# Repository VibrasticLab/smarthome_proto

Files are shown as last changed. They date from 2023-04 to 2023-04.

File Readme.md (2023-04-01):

# SmartHome Module

This repository contains development files for smarthome monitoring prototyping,
which intended for student final project.

Currently doesnt support any control mechanism, only measuring.

## Multi Module Version 1

### Sensors Options
- Temperature/Humidity Sensors (I2C)
    + HTU21D: [Tokped](https://www.tokopedia.com/akhishop/htu21d-temperature-and-humidity-sensor-module)
    + SHT20: [Tokped](https://www.tokopedia.com/akhishop/sht20-digital-temperature-and-humidity-sensor-module-i2c-communication)
    + SHT31-D: [Tokped](https://www.tokopedia.com/akhishop/sht31-d-temperature-humidity-sensor-module)
    + GY-213V: [Tokped](https://www.tokopedia.com/cncstorebandung/gy-213v-hdc1080-high-precision-temperature-and-humidity-sensor-module)
- Light Intensity Sensors (I2C)
    + GY302/BH1750: [Tokped](https://www.tokopedia.com/akhishop/gy-302-light-intensity-bh1750-module-sensor-intensitas-cahaya)
- CO2 Air (Analog)
    + MG-811: [Tokped](https://www.tokopedia.com/khursiot/dfrobot-analog-co2-gas-sensor-for-arduino-mg-811-sensor)
- MEMS Microphone (I2S)
    + INMP441: [Tokped](https://www.tokopedia.com/aifrobotic/inmp441-omnidirectional-microphone-module-mems-i2s-interface)

### ESP32 Pinout

NodeMCU Module: [Tokped](https://www.tokopedia.com/temins/esp32-esp-32-arduino-wifi-bluetooth-iot-development-board-micro-usb)

| I/O | Func | Connect |
|:---:|:----:|:---:|
| EN | RESET | Pull-up Button |
| 0 | FLASH | Pull-up Button |
| 1 | TX | UART0 |
| 2 | IND | LED |
| 3 | RX | UART0 |
| 13 | SPI WS | MIC |
| 14 | SPI SCK | MIC |
| 15 | BOOT-LOG | Pull-done Resistor |
| 21 | SDA | I2C Line |
| 22 | SCL | I2C Line |
| 23 | SPI DATA | MIC |
| 33 | ADC | VBAT |
| 34 | ADC | CO2 |

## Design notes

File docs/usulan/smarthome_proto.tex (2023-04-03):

\documentclass[a4paper,12pt,oneside,pdflatex,italian,final,twocolumn]{article}

\usepackage[utf8]{inputenc}
\usepackage{parallel}
\usepackage{siunitx}
\usepackage{booktabs}
\usepackage{fancyhdr}
\usepackage{subcaption}
\usepackage{listings}
\usepackage{hyperref}
\usepackage{pdfpages}
\usepackage{smartdiagram}
\usepackage{verbatim}

\usepackage[export]{adjustbox}
\usepackage[margin=0.5in]{geometry}
\addtolength{\topmargin}{0in}

\usepackage{libertine}
\renewcommand*\familydefault{\sfdefault}
\usepackage[T1]{fontenc}

\urlstyle{sf}
\hypersetup{
	colorlinks=true, %set true if you want colored links
	linktoc=all,     %set to all if you want both sections and subsections linked
	linkcolor=blue,  %choose some color if you want links to stand out
	urlcolor=blue,   %url color
}

\smartdiagramset{text width=2cm,module x sep= 3.4,back arrow disabled=true,}

\title{Smarthome Measurement Node Prototype}
\author{Achmadi ST MT}
\date{April 2023}

\begin{document}
	\pagestyle{fancy}

	\lhead{VibrasticLab}
	\chead{\today}
	\rhead{Specification Document v1.0}

	\onecolumn

	\begin{figure}

	\end{figure}\begin{minipage}{0.47\textwidth}
		\centering

	\end{minipage}
	\hfill
	\begin{minipage}{0.47\textwidth}
		\raggedleft
		\Huge \textbf{Smarthome Measurement Node}
	\end{minipage}

	\begin{figure}
		\begin{minipage}{0.47\textwidth}

			\section{Overview}
			\begin{itemize}
				\item Battery AAA Operated
				\item Low-Power WiFi Cient
				\item Re-Programmable Firmware
				\item Analog, I2S, and I2C interfaces
				\item Indicator LEDs Array
			\end{itemize}

		\end{minipage}
		\hfill
		\begin{minipage}{0.47\textwidth}
			\centering
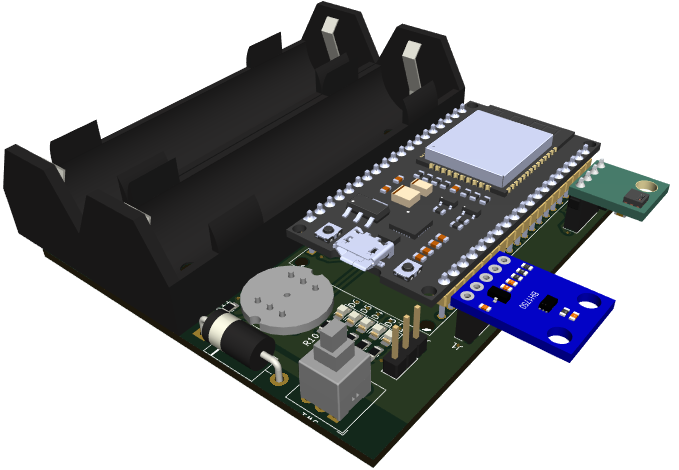
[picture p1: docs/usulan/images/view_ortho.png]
			

	\end{minipage}
	\end{figure}

	\raggedright
	\section{Main Unit Part}

	\centering
	\begin{figure}[!ht]
		\centering
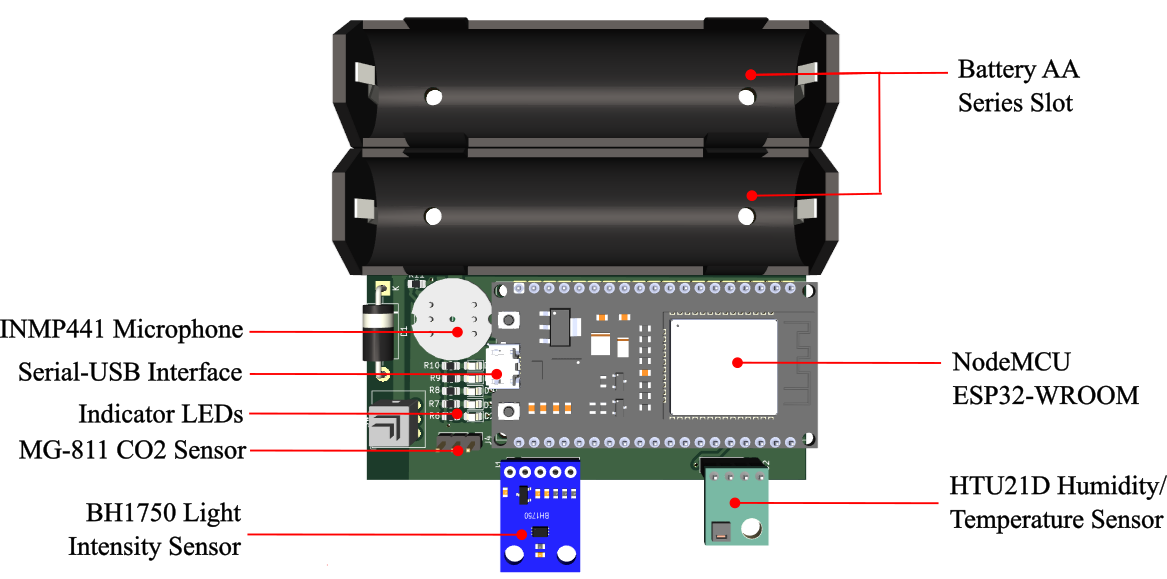
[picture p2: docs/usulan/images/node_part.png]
		
		\caption{Prototype Unit Parts}
	\end{figure}

	\raggedright
	\section{Data Exchange Flow}

	\smartdiagram[flow diagram:horizontal]{Multi Sensor Node,
		MQTT or HTTP Server, Data Bank Server, Data Fetch API, Python or Matlab Analysis}\\

	\vspace{5pt}

	\textbf{NOTES:} Its recommended to use Local Server infrastructure, preferably in accessable server room during development phase.

	\raggedright
	\section{PCB Design}

	\newpage
	\includepdf[pages=-,angle=-90]{pdf/nodemcu_based.pdf}

	\newpage
	\includepdf[pages=-,angle=-90]{pdf/bom.pdf}

	\raggedright
	\section{Project Repository}

	Current project repository: \href{https://github.com/VibrasticLab/smarthome_proto}{Github VibrasticLab}

	\raggedright
	\section{Development Constraints/Obstacles}

	Some development constraints/obstacles:

	\begin{itemize}
		\item Time span, including: PCB building time, firmware implementation, testing and calibration, server building.

		\item Calibration process, including: standards, controlled test environment, and already available measurement tools.

		\item Personel requirement, including: programmers (either embedded or backend server), project managers/administrator, purchasing staff, etc.

		\item Components handling, for example:

		\begin{itemize}
			\item MG-811 CO2 sensor requires heating to operate, thus consume high power from battery.

			\item MG-811 CO2 sensor are very expensive and limited local stock.

			\item Light Intensity might influenced by placement angle.

			\item Mic INMP411 requires good digital signal processing in embedded programming manner.
		\end{itemize}

	\end{itemize}

	\raggedright
	\section{Cost Estimation}

	\subsection{Unit Cost}

	\begin{tabular}{|l|l|l|}
		\toprule
		Item & Price-Qty & URL \\
		\midrule
		NodeMCU ESP32 & Rp. 66.800 & \href{https://www.tokopedia.com/temins/esp32-esp-32-arduino-wifi-bluetooth-iot-development-board-micro-usb}{Tokped} \\
		HTU21D & Rp. 35.000 & \href{https://www.tokopedia.com/akhishop/htu21d-temperature-and-humidity-sensor-module}{Tokped} \\
		BH1750 & Rp. 20.000 & \href{https://www.tokopedia.com/akhishop/gy-302-light-intensity-bh1750-module-sensor-intensitas-cahaya}{Tokped} \\
		MG-811 CO2 & Rp. 895.000 & \href{https://www.tokopedia.com/khursiot/dfrobot-analog-co2-gas-sensor-for-arduino-mg-811-sensor}{Tokped} \\
		R 0805 & Rp. 2.000 & \href{https://www.tokopedia.com/thingie/resistor-0805-5-102-1k-ohm-smd-2012}{Tokped} \\
		LED 0805 & Rp. 2.000 & \href{https://www.tokopedia.com/easyware-id/led-smd-0805-super-bright-all-color-led-smd-0805-semua-warna-putih}{Tokped} \\
		Diode 1N4007 & Rp. 500 & \href{https://www.tokopedia.com/dx-tronics/diode-1n4007-in4007-dioda-rectifier-1a-1000v}{Tokped} \\
		Mic INMP411 & Rp. 40.000 & \href{https://www.tokopedia.com/aifrobotic/inmp441-omnidirectional-microphone-module-mems-i2s-interface}{Tokped} \\
		Header/Cable/Switches & Rp. 50.000 & \href{https://www.tokopedia.com/eltech-online}{Tokped} \\
		PCB Fabrication & Rp. 50.000 & \href{https://www.tokopedia.com/geraicerdas/cetak-pcb-1-keping-single-double-layer-rapid-prototyping-satuan}{Tokped} \\
		Shipping Cost Overall & Rp. 50.000 & - \\
		\midrule
		Total & Rp. 1.211.300  & - \\
		\bottomrule
	\end{tabular}

	\vspace{5pt}
	\textbf{Notes:} Its recommended to build multiple units to monitor single room in different multiple placements.

	\subsection{Personel Cost}

	\begin{tabular}{|l|l|l|l|}
		\toprule
		Jobs & Price & Personel & Alternative \\
		\midrule
		PCB Assembly and QC & Rp. 1.000.000 & Achmadi & Tim LabFisis \\
		Firmware Developer & Rp. 2.000.000 & Achmadi & Tim Labkom \\
		Purchasing Staff & Rp. 500.000 & - & Asisten LabVibrastik \\
		Project Manager/Admin & Rp. 1.000.000 & Ammar & Asisten LabVibrastik \\
		Calibration Team & Rp. 1.000.000 & - &  Asisten LabVibrastik \\
		Backend Developer & Rp. 2.000.000 & Pras & Tim Labkom \\
		Server Infastructure Team & Rp. 500.000 & - & Tim Labkom \\
		\midrule
		Total & Rp. 8.000.000  & - & - \\
		\bottomrule
	\end{tabular}

	\vspace{5pt}
	\textbf{Note:} This the recommended jobdesc list, but the price here are only proposed estimation and still negotiable.

	\subsection{Development Cost}

	\begin{tabular}{|l|l|l|}
		\toprule
		Item & Qty & Price \\
		\midrule
		Measurement Node Cost & 5 prototype units & Rp. 6.056.500 \\
		Personel/Team & one-time project & Rp. 8.000.000 \\
		\midrule
		Total & - & Rp. 14.056.500 \\
		\bottomrule
	\end{tabular}
\end{document}

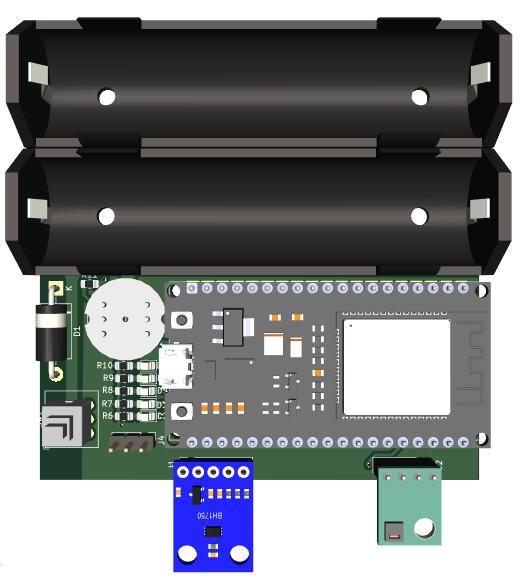
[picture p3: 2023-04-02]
docs/usulan/images/view_top.png

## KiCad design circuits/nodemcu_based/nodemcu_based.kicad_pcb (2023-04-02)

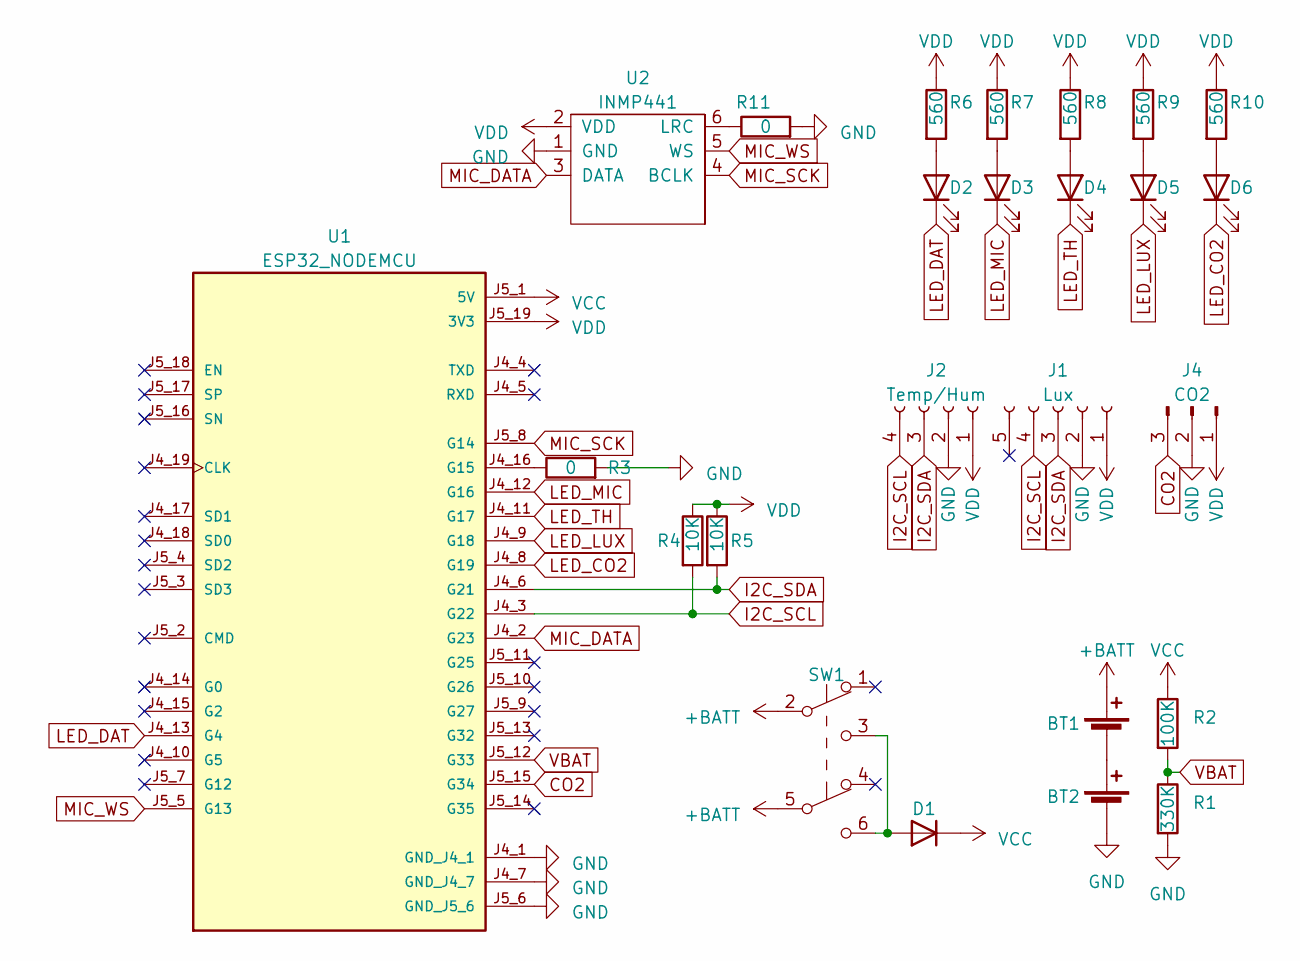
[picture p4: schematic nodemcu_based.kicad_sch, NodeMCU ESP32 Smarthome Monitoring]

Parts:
BT1, BT2: Battery_Cell; BatteryHolder_MPD_BH-18650-PC2
D1: D; D_DO-201_P15.24mm_Horizontal
D2, D3, D4, D5, D6: LED; LED_0805_2012Metric_Pad1.15x1.40mm_HandSolder
J1: Lux; PinSocket_1x05_P2.54mm_Vertical
J2: Temp/Hum; PinSocket_1x04_P2.54mm_Vertical
J4: CO2; PinHeader_1x03_P2.54mm_Vertical
R1: 330K; R_0805_2012Metric_Pad1.20x1.40mm_HandSolder
R2: 100K; R_0805_2012Metric_Pad1.20x1.40mm_HandSolder
R3, R11: 0; R_0805_2012Metric_Pad1.20x1.40mm_HandSolder
R4, R5: 10K; R_0805_2012Metric_Pad1.20x1.40mm_HandSolder
R6, R7, R8, R9, R10: 560; R_0805_2012Metric_Pad1.20x1.40mm_HandSolder
SW1: SW_Push_DPDT; SW_Push_2P2T_Toggle_CK_PVA2OAH5xxxxxxV2
U1: ESP32_NODEMCU; MODULE_ESP32_NODEMCU
U2: INMP441

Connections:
+BATT: BT1.1 (+), SW1.2 (B), SW1.5 (B)
CO2: J4.3, U1.J5_15 (G34)
GND: BT2.2 (-), J1.2, J2.2, J4.2, R1.2, R3.2, R11.2, U1.J4_1 (GND_J4_1), U1.J4_7 (GND_J4_7), U1.J5_6 (GND_J5_6), U2.1 (GND)
I2C_SCL: J1.4, J2.4, R4.2, U1.J4_3 (G22)
I2C_SDA: J1.3, J2.3, R5.2, U1.J4_6 (G21)
LED_CO2: D6.1 (K), U1.J4_8 (G19)
LED_DAT: D2.1 (K), U1.J4_13 (G4)
LED_LUX: D5.1 (K), U1.J4_9 (G18)
LED_MIC: D3.1 (K), U1.J4_12 (G16)
LED_TH: D4.1 (K), U1.J4_11 (G17)
MIC_DATA: U1.J4_2 (G23), U2.3 (DATA)
MIC_SCK: U1.J5_8 (G14), U2.4 (BCLK)
MIC_WS: U1.J5_5 (G13), U2.5 (WS)
unnamed: BT1.2 (-), BT2.1 (+)
unnamed: D1.2 (A), SW1.3 (C), SW1.6 (C)
unnamed: D2.2 (A), R6.2
unnamed: D3.2 (A), R7.2
unnamed: D4.2 (A), R8.2
unnamed: D5.2 (A), R9.2
unnamed: D6.2 (A), R10.2
unnamed: R3.1, U1.J4_16 (G15)
unnamed: R11.1, U2.6 (LRC)
VBAT: R1.1, R2.2, U1.J5_12 (G33)
VCC: D1.1 (K), R2.1, U1.J5_1 (5V)
VDD: J1.1, J2.1, J4.1, R4.1, R5.1, R6.1, R7.1, R8.1, R9.1, R10.1, U1.J5_19 (3V3), U2.2 (VDD)

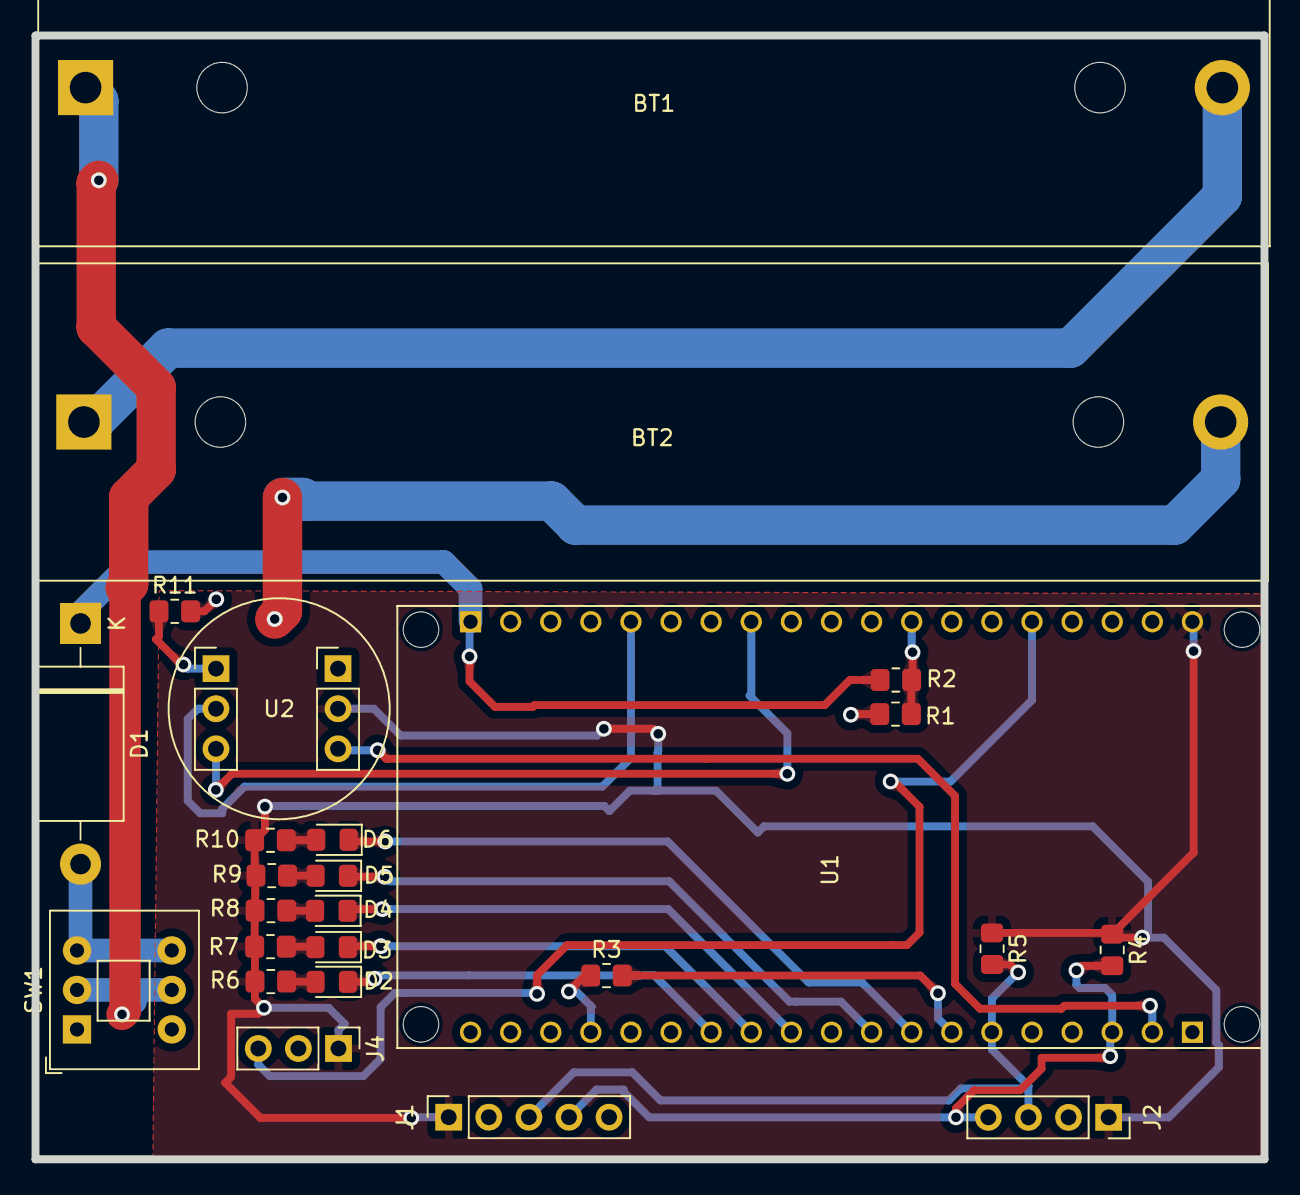
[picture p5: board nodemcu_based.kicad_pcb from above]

Board: 2 copper layers, 77.8 x 71.2 mm, 25 parts (0 on the bottom side), 25 nets.

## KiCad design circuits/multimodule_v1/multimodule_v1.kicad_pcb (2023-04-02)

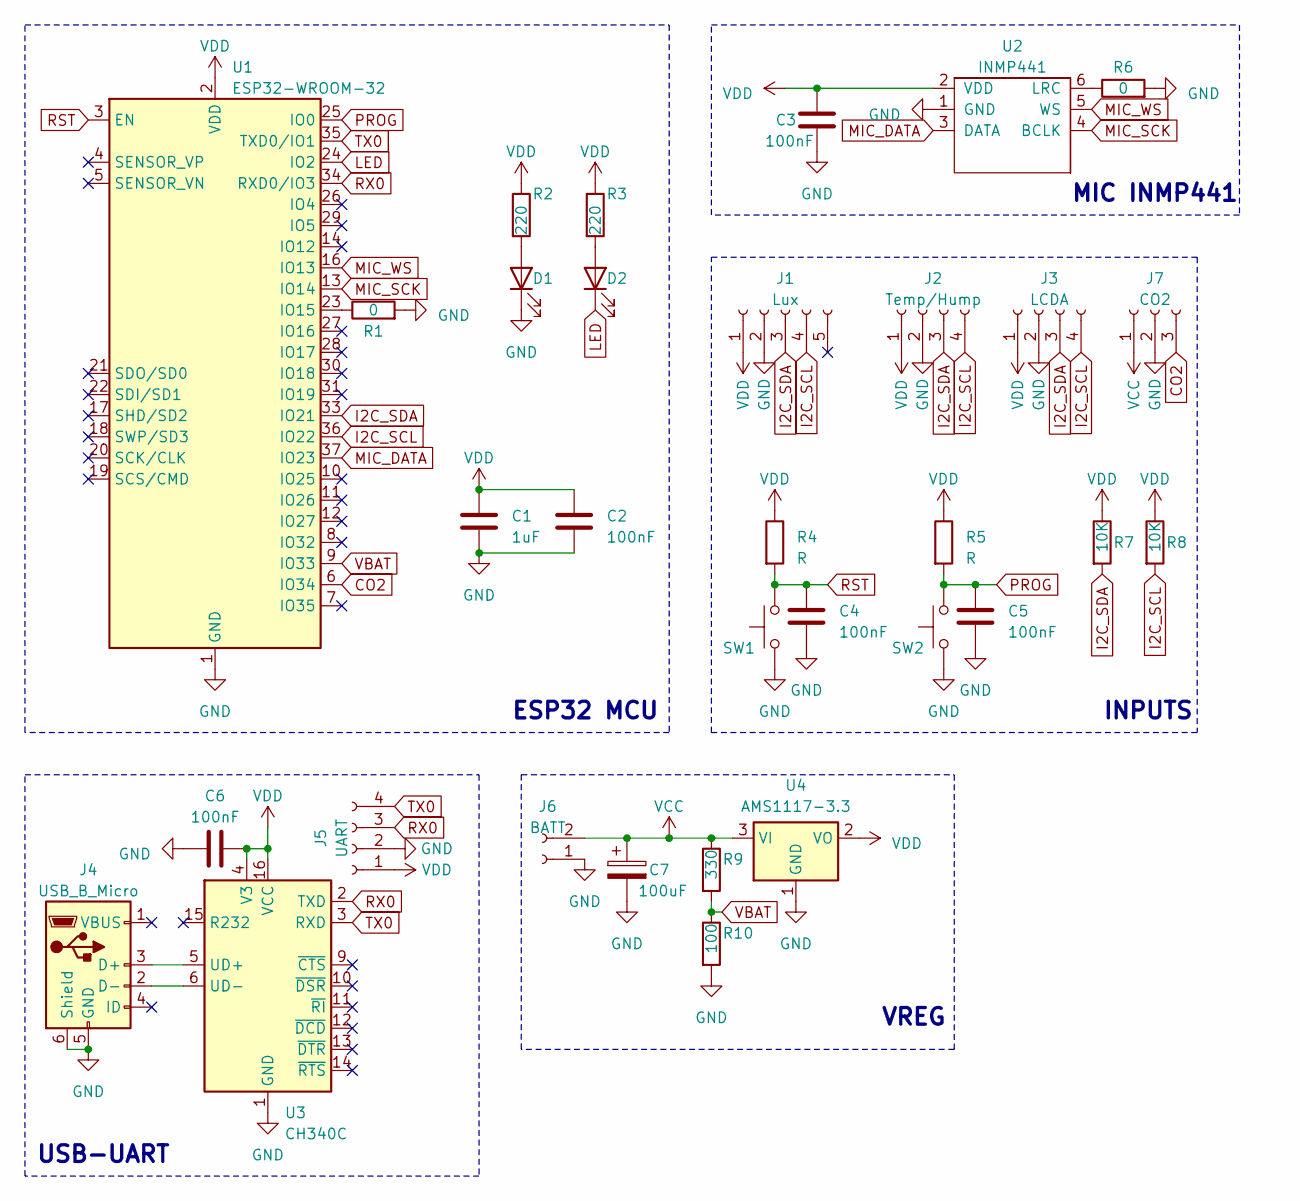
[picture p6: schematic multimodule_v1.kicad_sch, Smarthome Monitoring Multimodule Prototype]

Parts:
C1: 1uF; C_0805_2012Metric_Pad1.18x1.45mm_HandSolder
C2, C3, C4, C5, C6: 100nF; C_0805_2012Metric_Pad1.18x1.45mm_HandSolder
C7: 100uF; CP_Elec_4x5.8
D1, D2: LED; LED_0805_2012Metric_Pad1.15x1.40mm_HandSolder
J1: Lux; PinSocket_1x05_P2.54mm_Vertical
J2: Temp/Hump; PinSocket_1x04_P2.54mm_Vertical
J3: LCDA; PinSocket_1x04_P2.54mm_Vertical
J4: USB_B_Micro; USB_Micro-B_Wuerth_629105150521
J5: UART; PinHeader_1x04_P2.54mm_Vertical
J6: BATT; TerminalBlock_4Ucon_1x02_P3.50mm_Horizontal
J7: CO2; PinHeader_1x03_P2.54mm_Vertical
R1, R6: 0; R_0805_2012Metric_Pad1.20x1.40mm_HandSolder
R2, R3: 220; R_0805_2012Metric_Pad1.20x1.40mm_HandSolder
R4, R5: R; R_0805_2012Metric_Pad1.20x1.40mm_HandSolder
R7, R8: 10K; R_0805_2012Metric_Pad1.20x1.40mm_HandSolder
R9: 330; R_0805_2012Metric_Pad1.20x1.40mm_HandSolder
R10: 100; R_0805_2012Metric_Pad1.20x1.40mm_HandSolder
SW1, SW2: SW_Push; SW_PUSH_6mm
U1: ESP32-WROOM-32
U2: INMP441
U3: CH340C; SOIC-16_3.9x9.9mm_P1.27mm
U4: AMS1117-3.3; SOT-223-3_TabPin2

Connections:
CO2: J7.3, U1.6 (IO34)
GND: C1.2, C2.2, C3.2, C4.2, C5.2, C6.1, C7.2, D1.1 (K), J1.2, J2.2, J3.2, J4.5 (GND), J4.6 (Shield), J5.2, J6.1, J7.2, R1.2, R6.2, R10.2, SW1.1, SW2.1, U1.1 (GND), U1.15 (GND), U1.38 (GND), U1.39 (GND), U2.1 (GND), U3.1 (GND), U4.1 (GND)
I2C_SCL: J1.4, J2.4, J3.4, R8.2, U1.36 (IO22)
I2C_SDA: J1.3, J2.3, J3.3, R7.2, U1.33 (IO21)
LED: D2.1 (K), U1.24 (IO2)
MIC_DATA: U1.37 (IO23), U2.3 (DATA)
MIC_SCK: U1.13 (IO14), U2.4 (BCLK)
MIC_WS: U1.16 (IO13), U2.5 (WS)
unnamed: D1.2 (A), R2.2
unnamed: D2.2 (A), R3.2
unnamed: J4.3 (D+), U3.5 (UD+)
unnamed: J4.2 (D-), U3.6 (UD-)
unnamed: R1.1, U1.23 (IO15)
unnamed: R6.1, U2.6 (LRC)
PROG: C5.1, R5.2, SW2.2, U1.25 (IO0)
RST: C4.1, R4.2, SW1.2, U1.3 (EN)
RX0: J5.3, U1.34 (RXD0/IO3), U3.2 (TXD)
TX0: J5.4, U1.35 (TXD0/IO1), U3.3 (RXD)
VBAT: R9.2, R10.1, U1.9 (IO33)
VCC: C7.1, J6.2, J7.1, R9.1, U4.3 (VI)
VDD: C1.1, C2.1, C3.1, C6.2, J1.1, J2.1, J3.1, J5.1, R2.1, R3.1, R4.1, R5.1, R7.1, R8.1, U1.2 (VDD), U2.2 (VDD), U3.4 (V3), U3.16 (VCC), U4.2 (VO)

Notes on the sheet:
USB-UART
ESP32 MCU
VREG
INPUTS
MIC INMP441

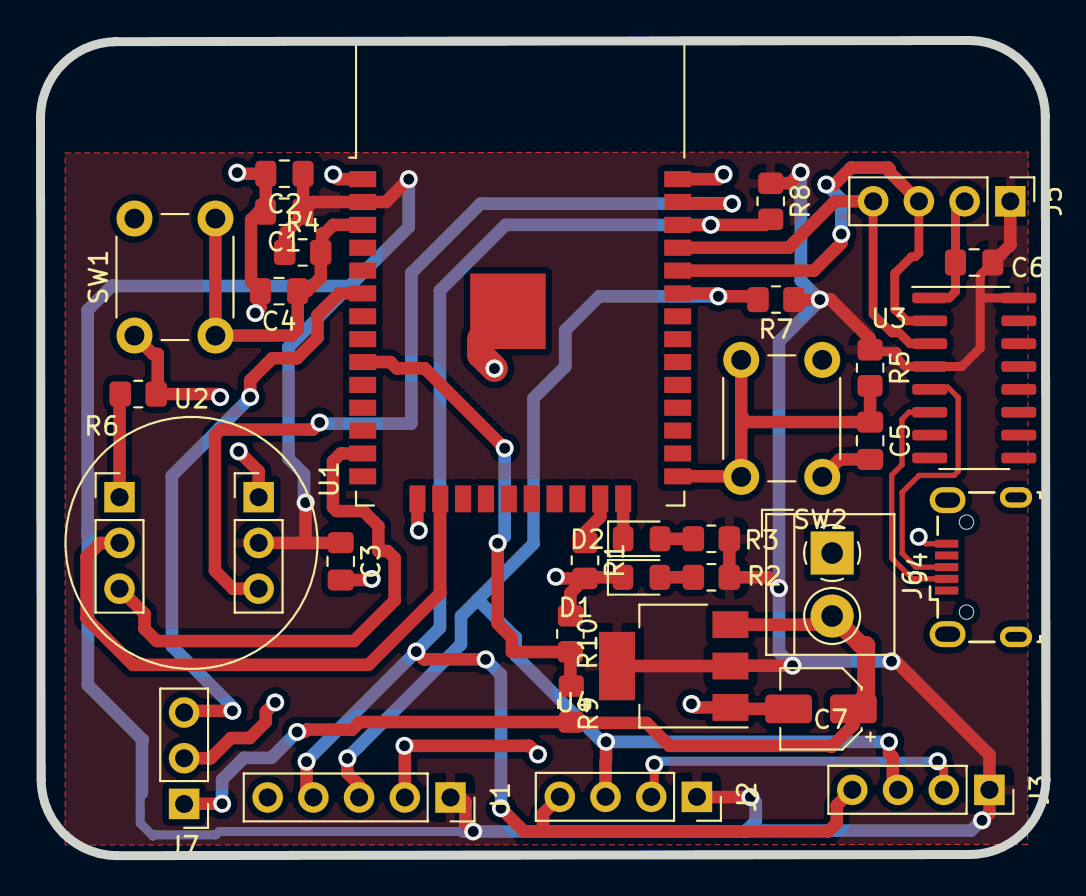
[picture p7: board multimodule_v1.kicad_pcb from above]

Board: 2 copper layers, 55.9 x 45.3 mm, 32 parts (0 on the bottom side), 21 nets.

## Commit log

2023-03-31 initial development
    [multimodule_v1.kicad_pcb, multimodule_v1.kicad_sch]
2023-04-01 Initial Schematic
    [multimodule_v1.kicad_sch]
2023-04-01 Initial Footprint
    [multimodule_v1.kicad_sch]
2023-04-01 Update Custom module
    [multimodule_v1.kicad_pcb, multimodule_v1.kicad_sch]
2023-04-01 NodeMCU ESP32 Based
    [nodemcu_based.kicad_pcb, nodemcu_based.kicad_sch]
2023-04-01 NOdeMCU Smarthome
    [nodemcu_based.kicad_pcb, nodemcu_based.kicad_sch]
2023-04-01 Tinggal Latex/PDF nya
    [nodemcu_based.kicad_pcb, nodemcu_based.kicad_sch]
2023-04-02 Small PCB version
    [multimodule_v1.kicad_pcb, multimodule_v1.kicad_sch]
2023-04-02 Nyicil Dokumen
    [nodemcu_based.kicad_pcb, nodemcu_based.kicad_sch]
2023-04-02 Dokumen Usulan
    [nodemcu_based.kicad_sch]
